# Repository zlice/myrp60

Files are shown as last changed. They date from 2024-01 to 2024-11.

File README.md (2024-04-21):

# RP2040 60% keyboard

60% keyboard with my preferred bottom/right layout.

Uses hacky wiring to save rows and push keys into other cols. This makes for a semi-weird layout in the keymap but it works fine.

# Kicad /jlcpcb

Everything is on one side so it is cheaper to fab and so you do not see chips or didodes.

- File > Fabcrication outputs > component placement (to /tmp/fireball-components)
- `./kicad_pos_to_cpl.py /tmp/myrp60-components/myrp60-top-pos.csv /tmp/myrp60-jlcpcb-placement-pos.cmp.csv` (not in repo)

# Build / Flash

`cp qmk/myrp60 <qmk_path>/keyboard`

`CFLAGS="-Wno-error=deprecated -Wp,-w" make myrp60`

mount and copy to rp2040 drive

# Shoutouts

- Jfedor for the PCB - https://github.com/jfedor2/rp2040-pmw3360
- QMK for the software/firmware and helpful community
- wokwi for the placement script - https://github.com/wokwi/kicad-jlcpcb-bom-plugin

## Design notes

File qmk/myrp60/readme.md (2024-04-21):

# myrp60

myrp60

*A short description of the keyboard/project*

* Keyboard Maintainer: [myrp60](https://github.com/zlice)
* Hardware Supported: *The PCBs, controllers supported*
* Hardware Availability: *Links to where you can find this hardware*

Make example for this keyboard (after setting up your build environment):

    make myrp60:default

Flashing example for this keyboard:

    make myrp60:default:flash

See the [build environment setup](https://docs.qmk.fm/#/getting_started_build_tools) and the [make instructions](https://docs.qmk.fm/#/getting_started_make_guide) for more information. Brand new to QMK? Start with our [Complete Newbs Guide](https://docs.qmk.fm/#/newbs).

## Bootloader

Enter the bootloader in 3 ways:

* **Bootmagic reset**: Hold down the key at (0,0) in the matrix (usually the top left key or Escape) and plug in the keyboard
* **Physical reset button**: Briefly press the button on the back of the PCB - some may have pads you must short instead
* **Keycode in layout**: Press the key mapped to `QK_BOOT` if it is available

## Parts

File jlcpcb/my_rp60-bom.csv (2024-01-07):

Comment | Designator | Footprint | JLCPCB Part #
TLV73333PDBV | U4 | SOT-23-5 | C134139
27 | R4,R3 | R_0402_1005Metric | C138021
30p | C19,C18 | C_0402_1005Metric | C1570
100n | C2,C4,C5,C9,C8,C6,C7,C1,C17,C3 | C_0402_1005Metric | C1525
 | D_D,D_<,D_ALT2,D_SHFT2,D_Q,D_O,D_E,D_3,D_I,D_C,D_M,D_/,D_DOWN,D_A,D_Y,D_U,D_2,D_G,D_MENU,D_P,D_R,D_CTRL,D_0,D_],D_UP,D_Z,D_LEFT,D_WIN,D_8,D_K,D_QUO,D_SPC,D_H,D_5,D_N,D_7,D_COL,D_>,D_TAB,D_RET,D_B,D_4,D_L,D_X,D_RGHT,D_[,D_6,D_1,D_ESC,D_9,D_T,D_F,D_S,D_-,D_SHFT1,D_BSPC,D_=,D_ALT1,D_J,D_W,D_V,D_FN,D_\ | D_SOD-123F | C402213
Crystal_GND24 | Y1 | Crystal_SMD_3225-4Pin_3.2x2.5mm | C9002
1u | C15,C13,C16,C10 | C_0402_1005Metric | C52923
W25Q128JVS | U5 | SOIC-8_5.23x5.23mm_P1.27mm | C97521
1k | R6,R7 | R_0402_1005Metric | C11702
RP2040 | U3 | RP2040-QFN-56 | C2040
10k | R5 | R_0402_1005Metric | C25744

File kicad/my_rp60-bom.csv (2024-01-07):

Id | Designator | Footprint | Quantity | Designation | Supplier and ref
1 | C2,C4,C5,C9,C8,C6,C7,C1,C17,C3 | C_0402_1005Metric | 10 | 100n | C1525
2 | C15,C13,C16,C10 | C_0402_1005Metric | 4 | 1u | C52923
3 | C19,C18 | C_0402_1005Metric | 2 | 30p | C1570
4 | U5 | SOIC-8_5.23x5.23mm_P1.27mm | 1 | W25Q128JVS | C97521
5 | R6,R7 | R_0402_1005Metric | 2 | 1k | C11702
6 | U3 | RP2040-QFN-56 | 1 | RP2040 | C2040
7 | R4,R3 | R_0402_1005Metric | 2 | 27 | C138021
8 | Y1 | Crystal_SMD_3225-4Pin_3.2x2.5mm | 1 | Crystal_GND24 | C9002
9 | SW2,SW1 | SW_SPST_Omron_B3FS-100xP | 2 | SW_Push | C271750
10 | R5 | R_0402_1005Metric | 1 | 10k | C25744
11 | U4 | SOT-23-5 | 1 | TLV73333PDBV | C134139

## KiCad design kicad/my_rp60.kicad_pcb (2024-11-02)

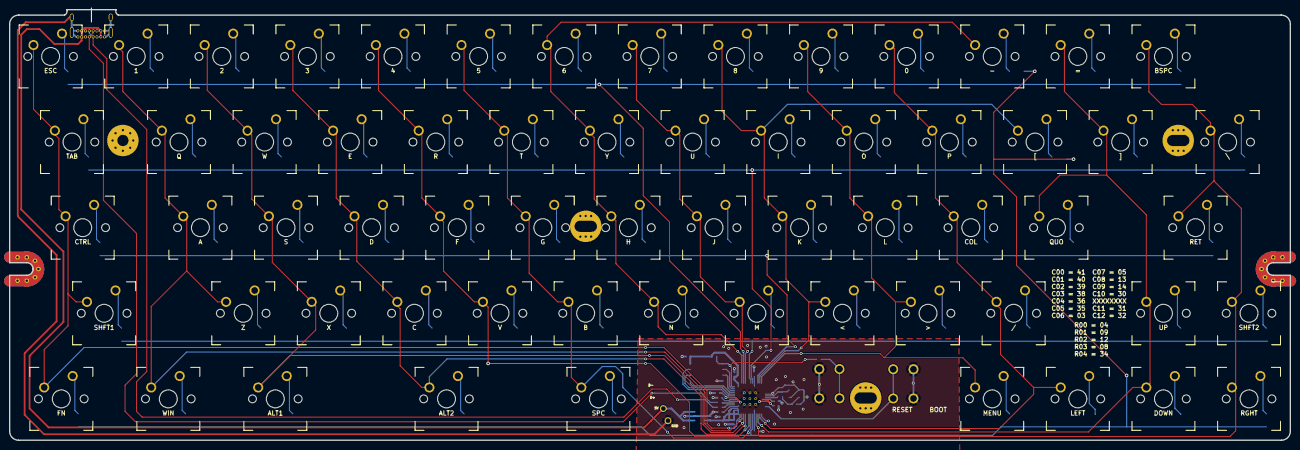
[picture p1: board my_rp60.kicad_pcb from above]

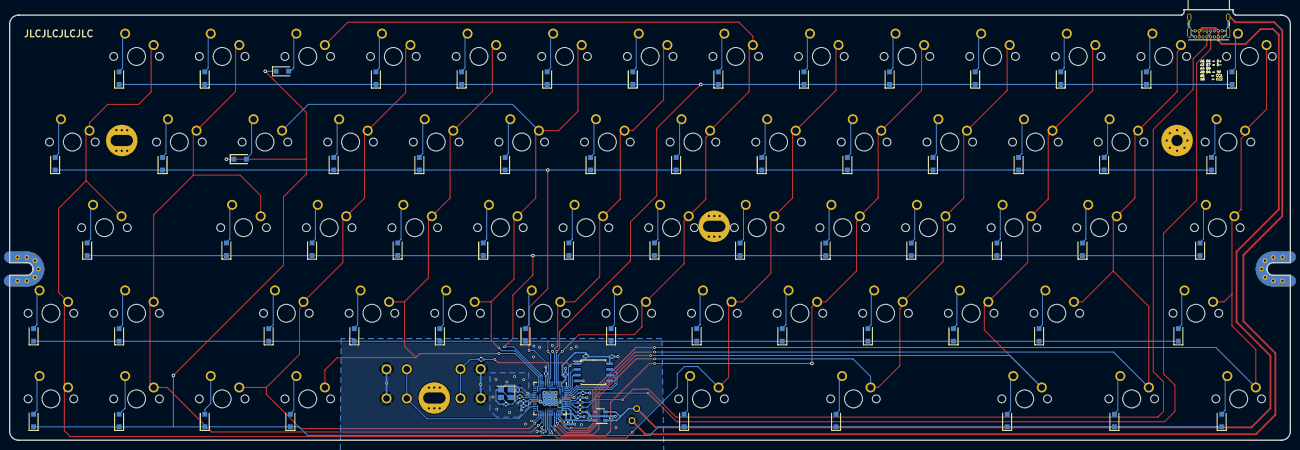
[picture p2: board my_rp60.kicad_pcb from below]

Board: 2 copper layers, 285.0 x 95.8 mm, 152 parts (89 on the bottom side), 36 nets.

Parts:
0, 1, 2, 3, 4, 5, 6, 7, 8, 9: SW_Cherry_MX_1.00u_PCB
-: SW_Cherry_MX_1.00u_PCB
/: SW_Cherry_MX_1.00u_PCB
<: SW_Cherry_MX_1.00u_PCB
=: SW_Cherry_MX_1.00u_PCB
>: SW_Cherry_MX_1.00u_PCB
A: SW_Cherry_MX_1.00u_PCB
ALT1, ALT2: MX-1.25U-NoLED
B: SW_Cherry_MX_1.00u_PCB
BSPC: SW_Cherry_MX_1.00u_PCB
C: SW_Cherry_MX_1.00u_PCB
C1, C2, C3, C4, C5, C6, C7, C8, C9, C17: 100n; C_0402_1005Metric
C10, C13, C15, C16: 1u; C_0402_1005Metric
C18, C19: 30p; C_0402_1005Metric
COL: SW_Cherry_MX_1.00u_PCB
CTRL: MX-1.75U-NoLED
D: SW_Cherry_MX_1.00u_PCB
DOWN: SW_Cherry_MX_1.00u_PCB
D_0, D_1, D_2, D_3, D_4, D_5, D_6, D_7, D_8, D_9: D_SOD-123F
D_-: D_SOD-123F
D_/: D_SOD-123F
D_<: D_SOD-123F
D_=: D_SOD-123F
D_>: D_SOD-123F
D_A: D_SOD-123F
D_ALT1, D_ALT2: D_SOD-123F
D_B: D_SOD-123F
D_BSPC: D_SOD-123F
D_C: D_SOD-123F
D_COL: D_SOD-123F
D_CTRL: D_SOD-123F
D_D: D_SOD-123F
D_DOWN: D_SOD-123F
D_E: D_SOD-123F
D_ESC: D_SOD-123F
D_F: D_SOD-123F
D_FN: D_SOD-123F
D_G: D_SOD-123F
D_H: D_SOD-123F
D_I: D_SOD-123F
D_J: D_SOD-123F
D_K: D_SOD-123F
D_L: D_SOD-123F
D_LEFT: D_SOD-123F
D_M: D_SOD-123F
D_MENU: D_SOD-123F
D_N: D_SOD-123F
D_O: D_SOD-123F
D_P: D_SOD-123F
D_Q: D_SOD-123F
D_QUO: D_SOD-123F
D_R: D_SOD-123F
D_RET: D_SOD-123F
D_RGHT: D_SOD-123F
D_S: D_SOD-123F
D_SHFT1, D_SHFT2: D_SOD-123F
D_SPC: D_SOD-123F
D_T: D_SOD-123F
D_TAB: D_SOD-123F
D_U: D_SOD-123F
D_UP: D_SOD-123F
D_V: D_SOD-123F
D_W: D_SOD-123F
D_WIN: D_SOD-123F
D_X: D_SOD-123F
D_Y: D_SOD-123F
D_Z: D_SOD-123F
D_[: D_SOD-123F
D_\: D_SOD-123F
D_]: D_SOD-123F
E: SW_Cherry_MX_1.00u_PCB
ESC: SW_Cherry_MX_1.00u_PCB
F: SW_Cherry_MX_1.00u_PCB
FN: MX-1.25U-NoLED
G: SW_Cherry_MX_1.00u_PCB
H: SW_Cherry_MX_1.00u_PCB
I: SW_Cherry_MX_1.00u_PCB
J: SW_Cherry_MX_1.00u_PCB
K: SW_Cherry_MX_1.00u_PCB
L: SW_Cherry_MX_1.00u_PCB
LEFT: SW_Cherry_MX_1.00u_PCB
M: SW_Cherry_MX_1.00u_PCB
MENU: SW_Cherry_MX_1.00u_PCB
N: SW_Cherry_MX_1.00u_PCB
O: SW_Cherry_MX_1.00u_PCB
P: SW_Cherry_MX_1.00u_PCB
Q: SW_Cherry_MX_1.00u_PCB
QUO: SW_Cherry_MX_1.00u_PCB
R: SW_Cherry_MX_1.00u_PCB
R3, R4: 27; R_0402_1005Metric
R5: 10k; R_0402_1005Metric
R6, R7: 1k; R_0402_1005Metric
RET: MX-2.25U-NoLED
RGHT: SW_Cherry_MX_1.00u_PCB
S: SW_Cherry_MX_1.00u_PCB
SHFT1: MX-2.25U-NoLED
SHFT2: SW_Cherry_MX_1.00u_PCB
SPC: MX-2U-NoLED
T: SW_Cherry_MX_1.00u_PCB
TAB: MX-1.5U-NoLED
U: SW_Cherry_MX_1.00u_PCB
U3: RP2040; RP2040-QFN-56
U4: TLV73333PDBV; SOT-23-5
U5: W25Q128JVS; SOIC-8_5.23x5.23mm_P1.27mm
UP: SW_Cherry_MX_1.00u_PCB
USB: USB_C_Receptacle_GCT_USB4085
V: SW_Cherry_MX_1.00u_PCB
W: SW_Cherry_MX_1.00u_PCB
WIN: MX-1.25U-NoLED
X: SW_Cherry_MX_1.00u_PCB
Y: SW_Cherry_MX_1.00u_PCB
Y1: Crystal_GND24; Crystal_SMD_3225-4Pin_3.2x2.5mm
Z: SW_Cherry_MX_1.00u_PCB
[: SW_Cherry_MX_1.00u_PCB
\: MX-1.5U-NoLED
]: SW_Cherry_MX_1.00u_PCB

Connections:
3: D_M.2, M.2
+1V1: C1.1, C2.1, C13.1, U3.23, U3.45, U3.50
+3V3: C3.1, C4.1, C5.1, C6.1, C7.1, C8.1, C9.1, C10.1, C16.1, C17.1, R5.1, U3.1, U3.10, U3.22, U3.33, U3.42, U3.43, U3.44, U3.48, U3.49, U4.5, U5.8
+5V: C15.1, U4.1, U4.3
D+: R3.1, USB.A6
D-: R4.1, USB.A7
GND: C1.2, C2.2, C3.2, C4.2, C6.2, C7.2, C8.2, C9.2, C10.2, C13.2, C15.2, C16.2, C17.2, C18.1, C19.2, U3.19, U3.57, U4.2, U5.4, Y1.2, Y1.4
unnamed: C19.1, R7.1, Y1.3
unnamed: R3.2, U3.47
unnamed: R4.2, U3.46
QSPI_SCLK: U3.52, U5.6
QSPI_SD0: U3.53, U5.5
QSPI_SD1: U3.55, U5.2
QSPI_SD2: U3.54, U5.3
QSPI_SD3: U3.51, U5.7
QSPI_SS: R5.2, R6.1, U3.56, U5.1
XIN: C18.2, U3.20, Y1.1
XOUT: R7.2, U3.21
c0: CTRL.1, ESC.1, FN.1, SHFT1.1, TAB.1, U3.41
c1: 1.1, A.1, Q.1, U3.40, WIN.1, Z.1
c2: 2.1, ALT1.1, S.1, U3.39, W.1, X.1
c3: 3.1, ALT2.1, C.1, D.1, E.1, U3.38
c4: 4.1, F.1, R.1, U3.36, V.1
c5: 5.1, B.1, G.1, SPC.1, T.1, U3.35
c6: 6.1, -.1, H.1, N.1, U3.3, Y.1
c7: 7.1, J.1, M.1, U.1, U3.5
c8: 8.1, <.1, I.1, K.1, U3.13, [.1
c9: 9.1, >.1, L.1, MENU.1, O.1, U3.14
c10: 0.1, /.1, COL.1, LEFT.1, P.1, U3.30
c11: =.1, DOWN.1, QUO.1, U3.31, UP.1, ].1
c12: BSPC.1, RET.1, RGHT.1, SHFT2.1, U3.32, \.1
r0: 0.2, 1.2, 2.2, 3.2, 4.2, 6.2, 7.2, 8.2, 9.2, =.2, BSPC.2, D_0.1, D_1.1, D_2.1, D_3.1, D_4.1, D_5.1, D_6.1, D_7.1, D_7.2, D_8.1, D_9.1, D_=.1, D_BSPC.1, D_ESC.1, ESC.2, U3.4
r1: D_E.1, D_I.1, D_O.1, D_P.1, D_Q.1, D_R.1, D_T.1, D_TAB.1, D_U.1, D_W.1, D_Y.1, D_\.1, D_\.2, D_].1, D_].2, E.2, I.2, O.2, P.2, Q.2, R.2, T.2, TAB.2, U.2, U3.9, W.2, Y.2, \.2, ].2
r2: A.2, COL.2, CTRL.2, D.2, D_A.1, D_A.2, D_COL.1, D_COL.2, D_CTRL.1, D_CTRL.2, D_D.1, D_D.2, D_F.1, D_F.2, D_G.1, D_G.2, D_H.1, D_H.2, D_J.1, D_J.2, D_K.1, D_K.2, D_L.1, D_L.2, D_QUO.1, D_QUO.2, D_RET.1, D_RET.2, D_S.1, D_S.2, F.2, G.2, H.2, J.2, K.2, L.2, QUO.2, RET.2, S.2, U3.12
r3: /.2, <.2, >.2, B.2, C.2, D_/.1, D_/.2, D_<.1, D_<.2, D_>.1, D_>.2, D_B.1, D_B.2, D_C.1, D_C.2, D_M.1, D_N.1, D_N.2, D_SHFT1.1, D_SHFT1.2, D_SHFT2.1, D_SHFT2.2, D_UP.1, D_UP.2, D_V.1, D_V.2, D_X.1, D_X.2, D_Z.1, D_Z.2, N.2, SHFT1.2, SHFT2.2, U3.8, UP.2, V.2, X.2, Z.2
r4: -.2, ALT1.2, ALT2.2, DOWN.2, D_-.2, D_ALT1.1, D_ALT1.2, D_ALT2.1, D_ALT2.2, D_DOWN.1, D_DOWN.2, D_FN.1, D_FN.2, D_LEFT.1, D_LEFT.2, D_MENU.1, D_MENU.2, D_RGHT.1, D_RGHT.2, D_SPC.1, D_SPC.2, D_WIN.1, D_WIN.2, D_[.2, FN.2, LEFT.2, MENU.2, RGHT.2, SPC.2, U3.34, WIN.2, [.2

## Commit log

2024-01-29 limit power and set polling rate
2024-11-02 kicad: oneside pcb
    [my_rp60.kicad_pcb]
